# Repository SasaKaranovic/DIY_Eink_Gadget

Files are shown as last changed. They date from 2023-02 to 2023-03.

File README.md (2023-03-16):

# DIY EINK GADGET

## What is this project about?

DIY Multifunctional Eink Gadget (https://youtu.be/i01PoMj23bA "DIY Multifunctional Eink Gadget")

Above video shows the finished E-INK gadget, how it works, how you can build one and motivation behind some of the design decisions.

## I like it! How can I build one?
The above video explains the idea and how hardware and firmware works. It's recommended that you watch that first.
Hardware and firmware build instructions and source files are available in their respective folders.

---

Blog page: https://sasakaranovic.com/projects/diy-eink-gadget/

YouTube video: https://youtu.be/i01PoMj23bA

---

#### Sasa Karanovic

<a href="https://sasakaranovic.com/" target="_blank" title="Sasa Karanovic Home Page"> Home Page</a> &nbsp;&middot;&nbsp; <a href="https://youtube.com/c/sasakaranovic" target="_blank" title="Sasa Karanovic on YouTube"> YouTube</a> &nbsp;&middot;&nbsp; <a href="https://github.com/sasakaranovic" target="_blank" title="Sasa Karanovic on GitHub"> GitHub</a> &nbsp;&middot;&nbsp; <a href="https://twitter.com/_sasakaranovic_" target="_blank" title="Sasa Karanovic on Twitter"> Twitter</a> &nbsp;&middot;&nbsp; <a href="https://instagram.com/_sasakaranovic_" target="_blank" title="Sasa Karanovic on Instagram"> Instagram</a> &nbsp;&middot;&nbsp; <a href="https://buymeacoffee.com/sasakaranovic" target="_blank" title="Sasa Karanovic on Buy me a coffee"> Buy me a coffee</a>

[home]: https://raw.githubusercontent.com/SasaKaranovic/common/master/assets/img_home.png "Sasa Karanovic Home Page"
[youtube]: https://raw.githubusercontent.com/SasaKaranovic/common/master/assets/img_youtube.png "Sasa Karanovic YouTube channel"
[github]: https://raw.githubusercontent.com/SasaKaranovic/common/master/assets/img_github.png "Sasa Karanovic on GitHub"
[twitter]: https://raw.githubusercontent.com/SasaKaranovic/common/master/assets/img_twitter.png "Sasa Karanovic on Twitter"
[instagram]: https://raw.githubusercontent.com/SasaKaranovic/common/master/assets/img_instagram.png "Sasa Karanovic on Instagram"
[coffee]: https://raw.githubusercontent.com/SasaKaranovic/common/master/assets/img_coffee.png "Buy me a coffee"

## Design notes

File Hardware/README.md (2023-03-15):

# Hardware folder contents

Folder structure

    Docs            → Datasheets for nRF microcontroller, display driver, e-ink display etc.
    Release         → Release/manufacturing packages (Gerbers, Pick-and-Place, Bill of Material etc)
    Source files    → Altium Designer Source files
    Schematic Print.PDF
    README.md

Release folder contains manufacturing releases for this project. If you want to order a board, this folder contains gerbers, bill of material, pick and place and any other manufacturing related document.

If you wish to modify the project, source files are available in the Source files folder. You could also use [online viewer](https://www.altium.com/viewer/) to view them online.

For convenience, there is also `Schematic Print.pdf` document that contains all the schematic documents in the `.pdf` format.

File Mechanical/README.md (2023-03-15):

# Mechanical/Enclosure folder contents

Folder structure

    STL         → STL/3MF files, ready for slicing and printing
    Fusion360   → Fusion360 design source file

STL folder contains `.stl` files if you wish to 3D print your own enclosure.

Fusion360 folder contains enclosure design source files that can be imported into Fusion360 if you wish to modify the design or inspect it in more detail.

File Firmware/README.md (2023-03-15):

# Development Environment

We are using nRF Connect SDK with Zephyr RTOS to build our project.

Please follow the Nordic's nRF Connect SDK [getting started guide](https://developer.nordicsemi.com/nRF_Connect_SDK/doc/latest/nrf/getting_started.html) on how to install and setup development environment.

We are using the following SDK and Zephyr version
nRF Connect SDK version: 2.3.99
Zephyr version: 3.2.99

# How to build firmware

Once you have the build environment setup, you can simply navigate to `Firmware` folder and compile the code by running `west build -b nrf52dk_nrf52810` command
After a few seconds you should see a message that looks something like this
```
[183/183] Linking C executable zephyr\zephyr.elf
Memory region         Used Size  Region Size  %age Used
           FLASH:      111484 B       192 KB     56.70%
             RAM:       16936 B        24 KB     68.91%
        IDT_LIST:          0 GB         2 KB      0.00%
```
This means you have succesfully compiled the firmware and you are ready to flash it onto your board.

# How to flash firmware

We are using J-Link programmer to flash firmware onto our boards.
Simply connect the J-Link programmer to your board, provide power to the e-ink gadget and run `west flash` to flash latest binary onto your board.

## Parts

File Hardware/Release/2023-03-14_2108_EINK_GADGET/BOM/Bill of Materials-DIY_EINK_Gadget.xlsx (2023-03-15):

Designator | Description | Distributor | Distributor Part Number | Manufacturer | Manufacturer Part Number | Quantity
A1 | 2.4GHz - Chip RF Antenna 2.4GHz ~ 2.5GHz 0.5dBi Solder Surface Mount | DigiKey | 712-1006-1-ND | Johanson Technology Inc. | 2450AT18B100E | 1
C2, C3, C4, C5 | Capacitor | DigiKey | 1276-2138-1-ND | Samsung Electro-Mechanics | CL10C070DB8NNNC | 4
C6, C7, C8, C12, C25, C27 | Capacitor | DigiKey | 1276-1935-1-ND | Samsung Electro-Mechanics | CL10B104KB8NNWC | 6
C9, C24, C26, C28, C29 | Capacitor | DigiKey | 1276-2087-1-ND | Samsung Electro-Mechanics | CL10B475KQ8NQNC | 5
C11, C15, C16, C17, C18, C19, C20, C21, C22 | Capacitor | DigiKey | 1276-6617-1-ND | Samsung Electro-Mechanics | CL10B105KA8VPNC | 9
C14 | Capacitor | DigiKey | 1276-1008-1-ND | Samsung Electro-Mechanics | CL10C101JB8NNNC | 1
C23 | Capacitor | DigiKey | 1276-2083-1-ND | Samsung Electro-Mechanics | CL10B474KA8NNNC | 1
D1, D2, D3 |  | DigiKey | NRVB130LSFT1GOSCT-ND | onsemi | NRVB130LSFT1G | 3
D4 | Typical RED GaAs LED | DigiKey | Lite-On Inc. | Lite-On Inc. | LTST-C193KRKT-5A | 1
L1, L5 | Inductor | DigiKey | 311-0.0HRCT-ND | YAGEO | RC0603FR-070RL | 2
L2 | Inductor | DigiKey | 535-12249-1-ND | Abracon LLC | ASMCI-0603-100M-T | 1
L3 | Inductor | DigiKey | 535-11540-1-ND | Abracon LLC | AIMC-0603-3N9S-T | 1
L4 | Inductor | DigiKey | 445-8747-1-ND | TDK Corporation | VLCF5024T-470MR40-2 | 1
P2 |  | DigiKey | 609-SFV24R-4STE1HLFCT-ND | Amphenol ICC (FCI) | SFV24R-4STE1HLF | 1
P3 | CONN RCPT USB2.0 TYPEC 5A | DigiKey | 2073-USB4105-GF-ACT-ND | GCT | USB4105-GF-A | 1
Q1 | MOSFET N-CH 60V 0.38A | DigiKey | DMN62D0U-13DICT-ND | Diodes Incorporated | DMN62D0U-13 | 1
R3 | Resistor | DigiKey | 311-2.2HRCT-ND | YAGEO | RC0603FR-072R2L | 1
R4 | Resistor | DigiKey | 13-AC0603FR-1022KLCT-ND | YAGEO | AC0603FR-1022KL | 1
R5 | Resistor | DigiKey | 13-RC0603FR-10470RLCT-ND | YAGEO | RC0603FR-10470RL | 1
R6, R7 | Resistor | DigiKey | 13-RC0603FR-135K1LCT-ND | YAGEO | RC0603FR-135K1L | 2
R10 | Resistor | DigiKey | 311-68.0KHRCT-ND | YAGEO | RC0603FR-0768KL | 1
R11 | Resistor | DigiKey | 311-100KHRCT-ND | YAGEO | RC0603FR-07100KL | 1
SW1, SW2, SW3 | SWITCH TACTILE SPST-NO 0.05A 12V | DigiKey | CKN9088CT-ND | C&K | PTS645SL50SMTR92 LFS | 3
U1 | IC RF TxRx + MCU Bluetooth Bluetooth v5.0 2.4GHz 32-VFQFN Exposed Pad | DigiKey | 1490-NRF52810-QCAA-RCT-ND | Nordic Semiconductor ASA | NRF52810-QCAA-R | 1
U2 | Linear Voltage Regulator IC 1 Output 450mA SOT-23-5 | DigiKey | NCP161ASN330T1GOSCT-ND | ON Semiconductor | NCP161ASN330T1G | 1
U3 | 1xLi-Ion char, 0.5A, 4.2V reg, 3.75-6V | DigiKey | MCP73832T-2ACI/OTCT-ND | Microchip Technology | MCP73832T-2ACI/OT | 1
X1, X2 | 32.768 kHz ±20ppm Crystal 7pF 70 kOhms 2-SMD, No Lead, 32 MHz ±10ppm Crystal 8pF 50 Ohms 4-SMD, No Lead | DigiKey | XC3067CT-ND | ECS Inc. | ECS-320-8-37B-CKY-TR | 2

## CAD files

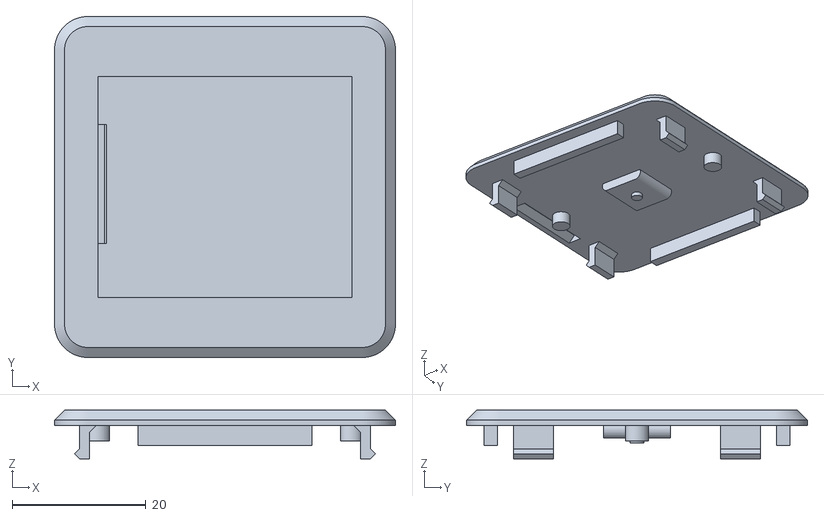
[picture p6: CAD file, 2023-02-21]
Mechanical/STL/Top-Actuator.stl
51.0 x 51.0 x 7.30

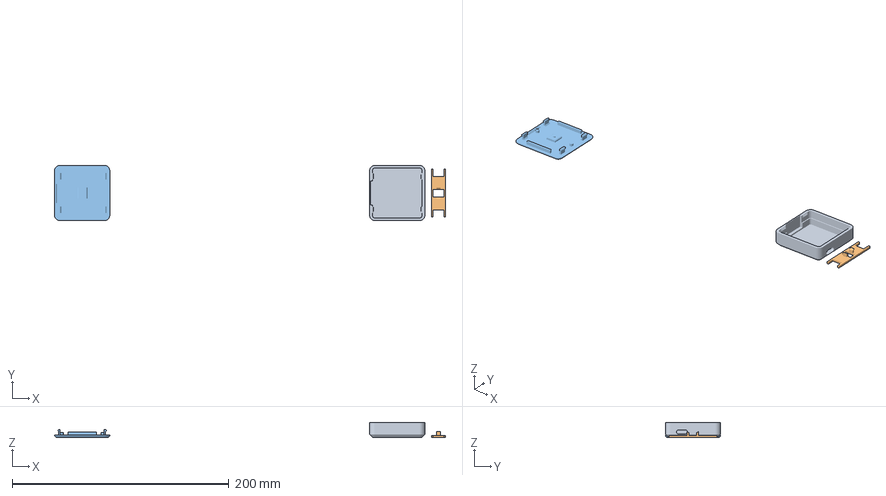
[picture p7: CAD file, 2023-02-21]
Mechanical/STL/Enclosure.3mf
360.5 x 51.0 x 14.0 mm
Bottom Enclosure.stl
Switch-Insert.stl
Top-Actuator.stl

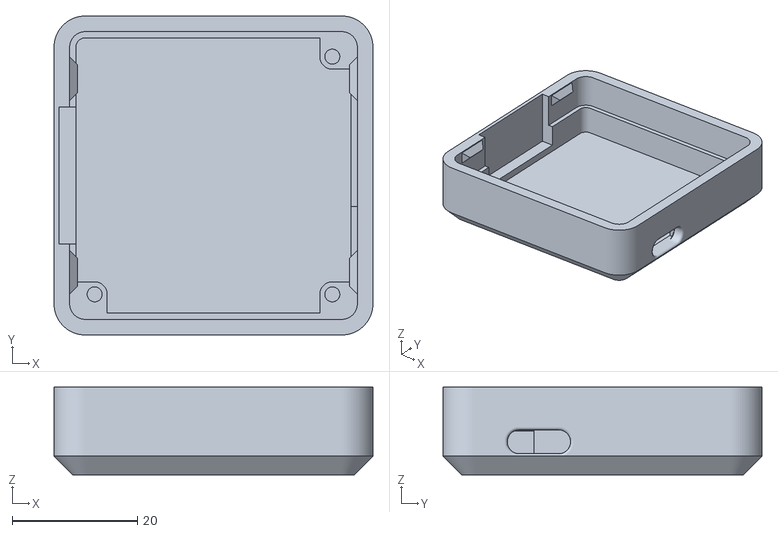
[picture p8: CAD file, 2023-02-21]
Mechanical/STL/Bottom Enclosure.stl
51.0 x 51.0 x 14.0

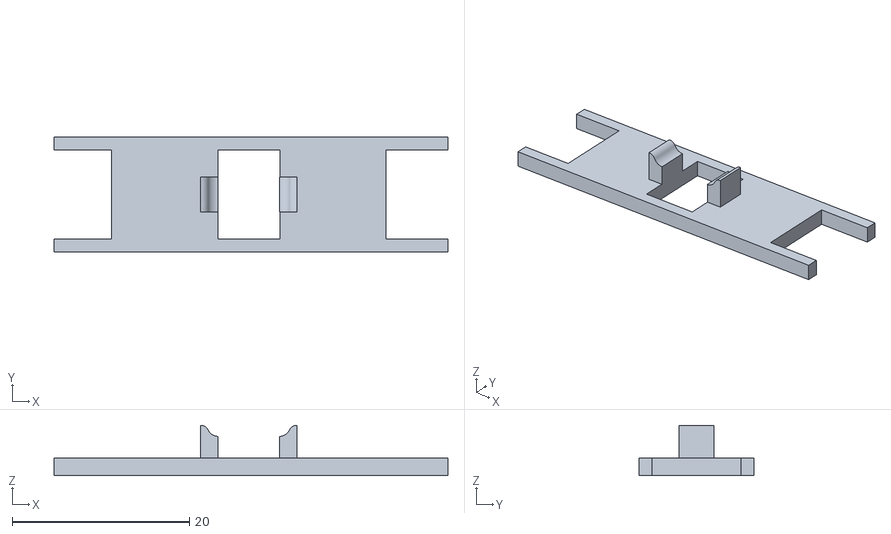
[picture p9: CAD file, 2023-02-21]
Mechanical/STL/Switch-Insert.stl
44.5 x 13.0 x 5.70

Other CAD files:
Mechanical/Fusion360/Enclosure.f3z

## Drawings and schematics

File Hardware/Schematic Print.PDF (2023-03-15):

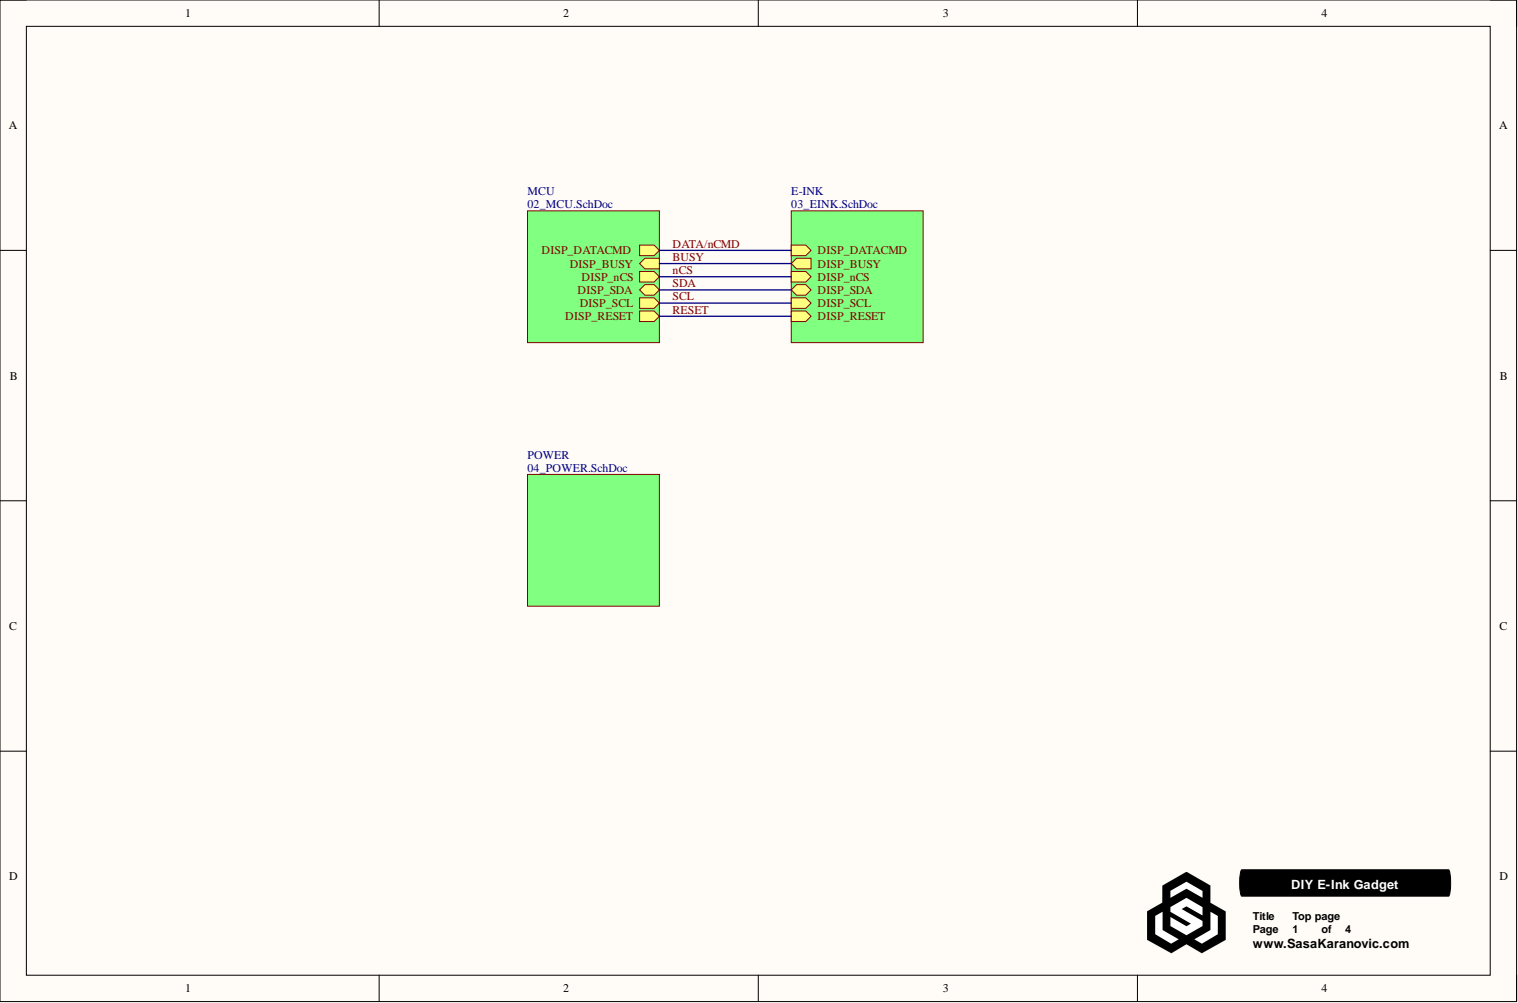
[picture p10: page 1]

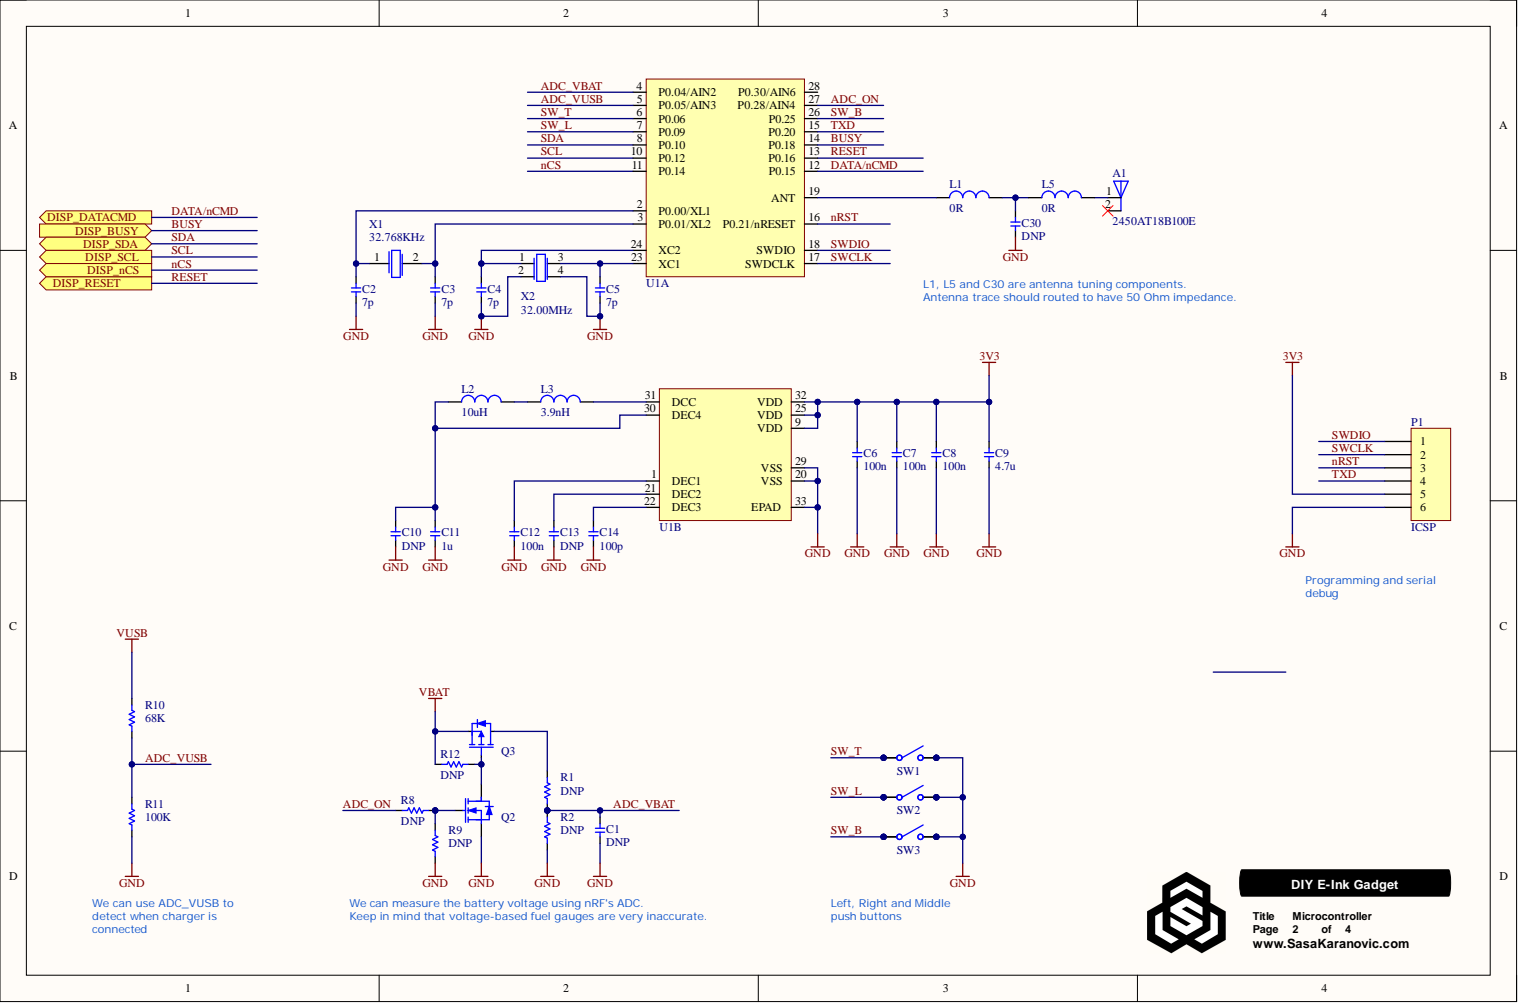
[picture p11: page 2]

C4 7p

L1, L5 and C30 are antenna tuning components.
Antenna trace should routed to have 50 Ohm impedance.

GND
We can use ADC_VUSB to
detect when charger is
connected

We can measure the battery voltage using nRF's ADC.
Keep in mind that voltage-based fuel gauges are very inaccurate.

Left, Right and Middle
push buttons

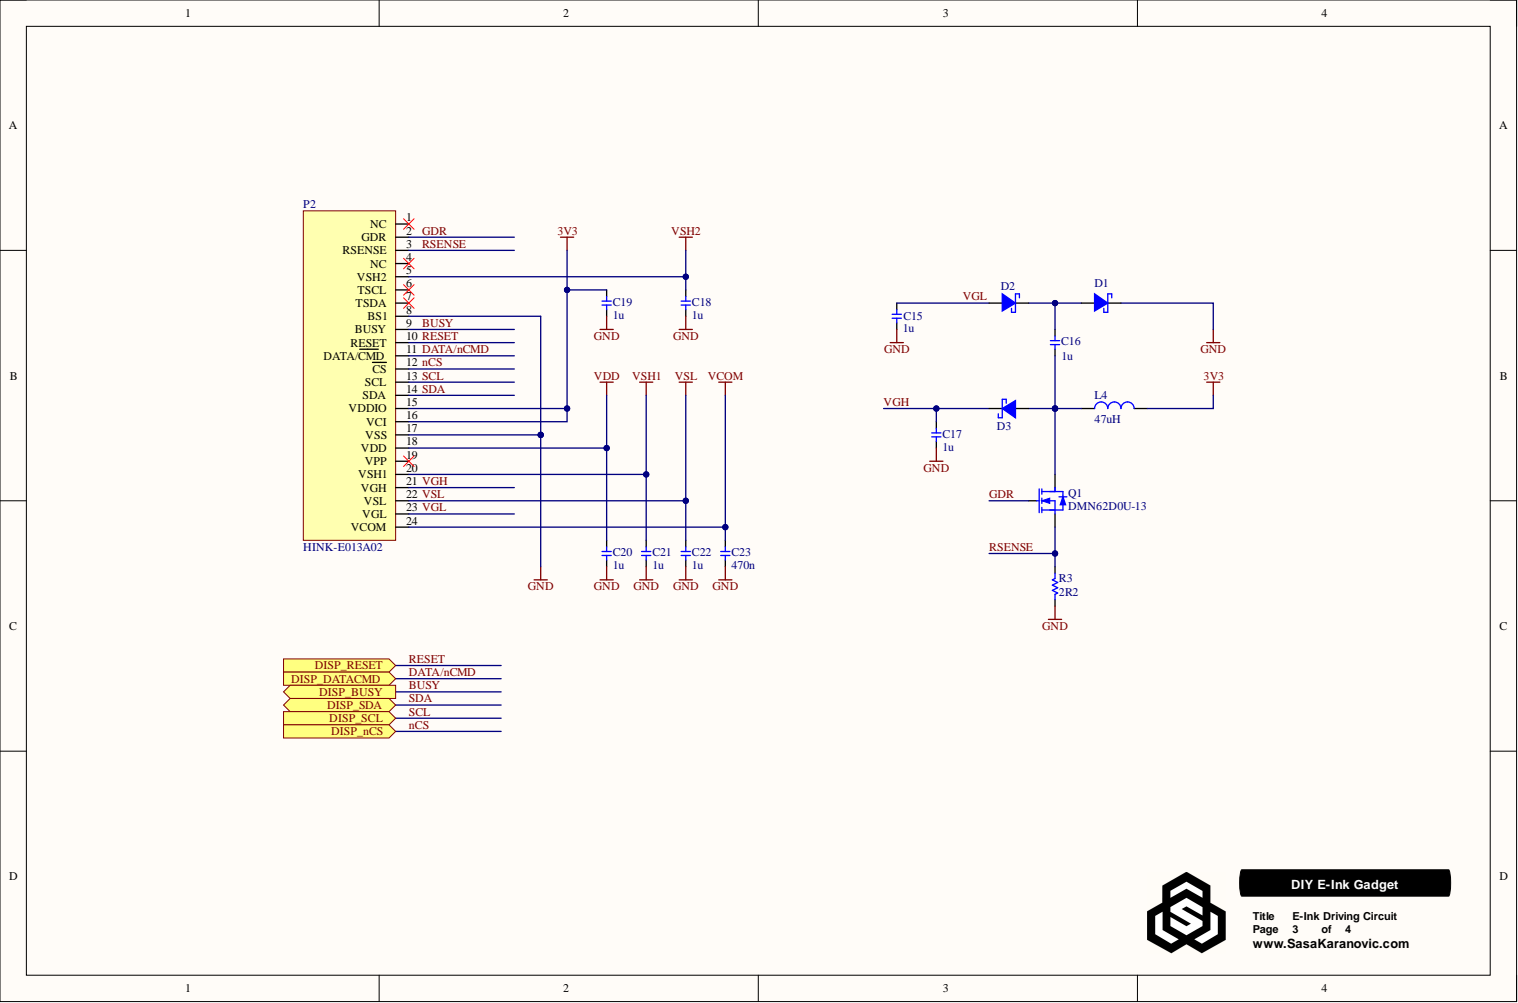
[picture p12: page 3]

9 BU S Y 1 0 RESE T 1 1 D ATA / n C M D 1 2 nCS 1 3 SCL 1 4 SD A

1 5
1 6
1 7
1 8
1 9 0

2 1 V G H 2 2 VSL VGL

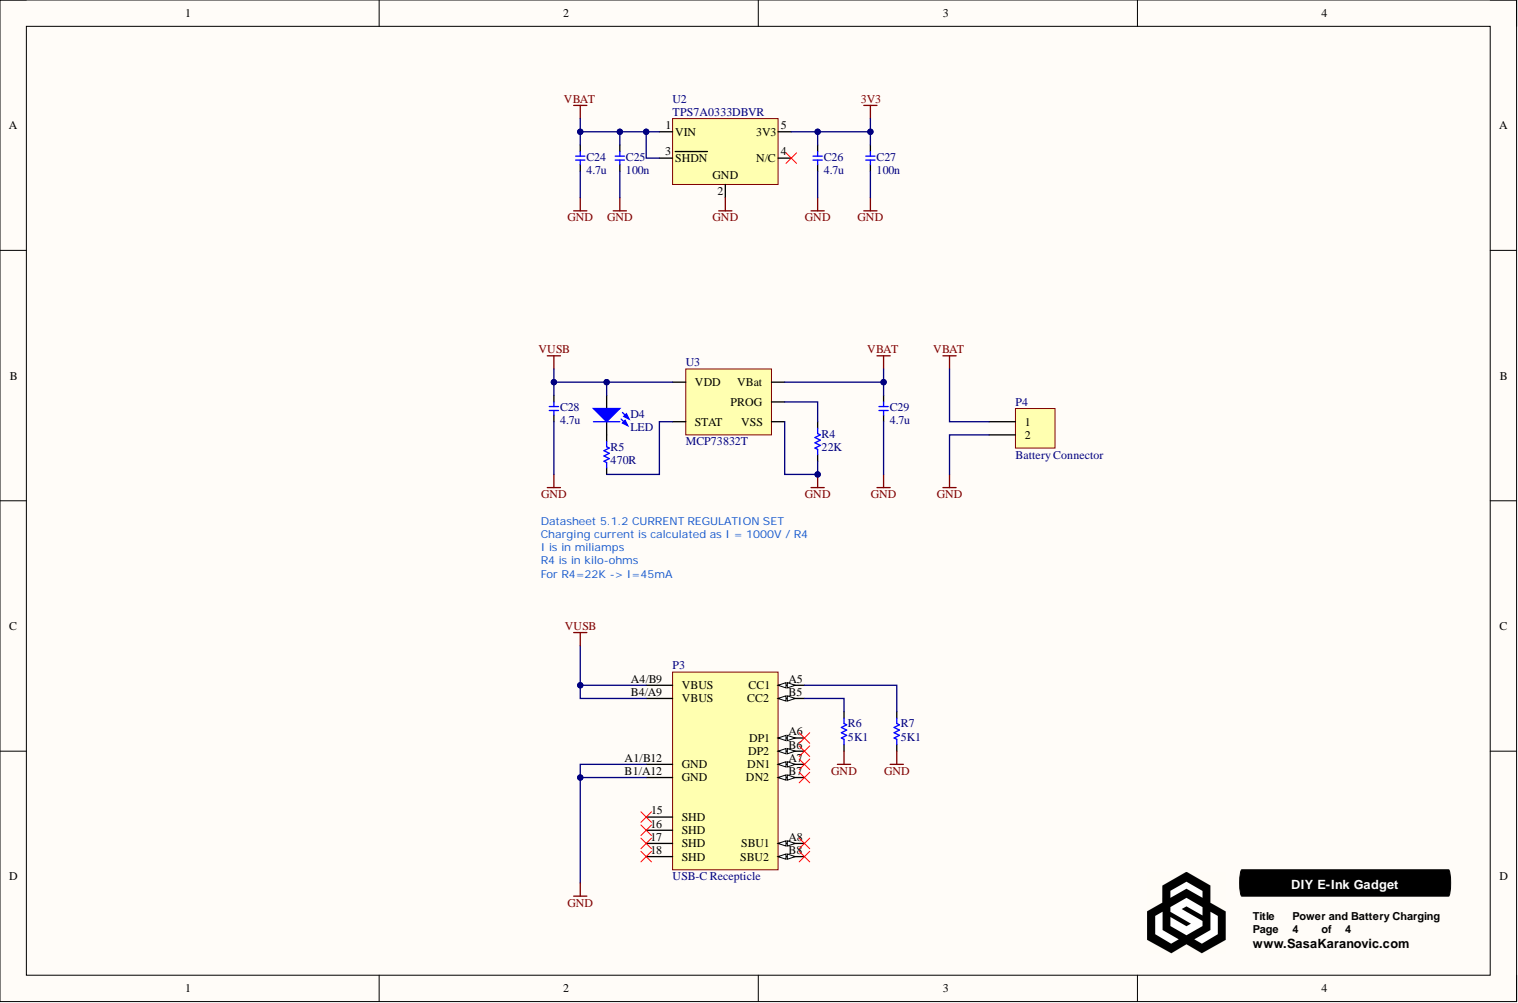
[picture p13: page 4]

Datasheet 5.1.2 CURRENT REGULATION SET
Charging current is calculated as I = 1000V / R4
I is in miliamps
R4 is in kilo-ohms
For R4=22K -> I=45mA

GND B1/A12

SHD 15

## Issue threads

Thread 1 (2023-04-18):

Is this project open source hardware and/or open source software?

abetusk, 2023-04-18:
From the [YouTube video](https://www.youtube.com/watch?v=i01PoMj23bA):

> ... as always the entire project is open source open hardware so you can easily make any changes or improvements ...

As of this writing, this project is, as far as I can tell, "closed source" (at least here in the US) since there is no indication about what license is that the project falls under. I don't see a LICENSE file for the project nor do I see license file headers in the source files. If I've missed these, my apologies.

"Open Source" has a generally accepted meaning of being able to use the digital artifacts for commercial purposes. The [OSI](https://opensource.org/osd/) and Wikipedia's entry on [open-source licensing](https://en.wikipedia.org/wiki/Open-source_license) both articulate that commercial re-use is a (generally accepted) requirement of an "open source" license.

The [Open Source Hardware Association](https://www.oshwa.org/definition/) articulates requirements of design files to meet their "open source" standards:

> Open source hardware is hardware whose design is made publicly available so that anyone can study, modify, distribute, make, and sell the design or hardware based on that design.

Without licensing information about the various digital artifacts (BOM, schematic, Gerbers, source code, etc.), the default is for them to fall under copyright protection and are not allowed to be copied, modified or distributed without explicit consent.

Was the intent to make this project libre/free/open source software/hardware?

If so, could you indicate the license, either by providing a LICENSE file with the appropriate license or by putting a license preamble in each of the source files (preferably both).

If not, it might be good to clarify what the restrictions are to avoid confusion. For example, indicating that the source is available, rather than it being open source.

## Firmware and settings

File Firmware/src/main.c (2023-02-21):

#include <zephyr/logging/log.h>
LOG_MODULE_REGISTER(app, LOG_LEVEL_INF);

#include <zephyr/kernel.h>
#include <zephyr/device.h>
#include <zephyr/devicetree.h>
#include <zephyr/init.h>
#include <zephyr/pm/pm.h>
#include <zephyr/pm/device.h>
#include <zephyr/pm/policy.h>
#include <soc.h>
#include "retained.h"
#include <stdio.h>
#include <string.h>
#include "board.h"
#include "ssd1680.h"
#include "gfx.h"
#include "gfx_icon.h"
#include "screen_controller.h"
#include "screen_game_dashboard.h"

/* Prevent deep sleep (system off) from being entered on long timeouts
 * or `K_FOREVER` due to the default residency policy.
 *
 * This has to be done before anything tries to sleep, which means
 * before the threading system starts up between PRE_KERNEL_2 and
 * POST_KERNEL.  Do it at the start of PRE_KERNEL_2.
 */
static int disable_ds_1(const struct device *dev)
{
    ARG_UNUSED(dev);
    pm_policy_state_lock_get(PM_STATE_SOFT_OFF, PM_ALL_SUBSTATES);
    return 0;
}

SYS_INIT(disable_ds_1, PRE_KERNEL_2, 0);

static void reset_to_main_menu(void)
{
    LOG_INF("Resetting to setup menu");
    retained.app_state = 0;             // Reset app state to main-menu
    retained.current_selection = 1;     // Set first menu item as selected
    retained_update();                  // Update retained section
    button_state.left = false;          // Clear left button press
    button_state.middle = false;        // Clear middle button press
    button_state.right = false;         // Clear right button press
}

void main(void)
{
    // Wake up time is 16.8us so we should be able to capture button press
    // First get the GPIO state before going forward
    board_switch_init();
    board_update_button_states();

    // Initialize rest of the board
    board_gpio_init();
    gfx_initialize();

    // Validate retained data
    bool retained_ok = retained_validate();
    retained.boots += 1;
    retained_update();

    LOG_INF("Left: %s", button_state.left ? "On" : "Off");
    LOG_INF("Middle: %s", button_state.middle ? "On" : "Off");
    LOG_INF("Right: %s", button_state.right ? "On" : "Off");

    LOG_INF("Retained data: %s", retained_ok ? "valid" : "INVALID");
    LOG_INF("Boot count: %u", retained.boots);
    LOG_INF("Off count: %u", retained.off_count);
    LOG_INF("App state: %u", retained.app_state);
    LOG_INF("Selection: %u", retained.current_selection);

    // Check if middle button is held for 3+ sec
    uint8_t nMiddleCount=0;
    while( board_button_is_pressed(BUTTON_MIDDLE) )
    {
        nMiddleCount++;
        k_sleep(K_MSEC(500));
        if(nMiddleCount>=6)
        {
            reset_to_main_menu();
            break;
        }
    }

    // Update the screen based on state of the device
    screen_logic_state_tick();

    // Put screen and the device into deep sleep
    eink_deep_sleep();
    LOG_INF("Entering deep sleep mode. Night night.");
    pm_state_force(0u, &(struct pm_state_info){PM_STATE_SOFT_OFF, 0, 0});

    while (1)
    {
        k_sleep(K_MSEC(500));
    }
}

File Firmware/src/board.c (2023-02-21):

#include <zephyr/logging/log.h>
LOG_MODULE_REGISTER(board, LOG_LEVEL_INF);

#include <zephyr/kernel.h>
#include <zephyr/device.h>
#include <zephyr/devicetree.h>
#include <zephyr/drivers/gpio.h>
#include <zephyr/drivers/spi.h>
#include <hal/nrf_gpio.h>
#include <stdio.h>
#include <string.h>
#include "board.h"

#define SPIBB_NODE  DT_NODELABEL(spibb0)
static const struct device *const dev_spibb = DEVICE_DT_GET(SPIBB_NODE);

#define LED0_NODE DT_ALIAS(led0)
static const struct gpio_dt_spec led = GPIO_DT_SPEC_GET(LED0_NODE, gpios);

#define EINK_RESET DT_ALIAS(einkreset)
static const struct gpio_dt_spec dev_eink_reset = GPIO_DT_SPEC_GET(EINK_RESET, gpios);

#define EINK_BUSY DT_ALIAS(einkbusy)
static const struct gpio_dt_spec dev_eink_busy = GPIO_DT_SPEC_GET(EINK_BUSY, gpios);

#define EINK_DC DT_ALIAS(einkdc)
static const struct gpio_dt_spec dev_eink_dc = GPIO_DT_SPEC_GET(EINK_DC, gpios);


struct spi_cs_control cs_ctrl = (struct spi_cs_control){
    .gpio = GPIO_DT_SPEC_GET(SPIBB_NODE, cs_gpios),
    .delay = 0u,
};


// Buttons
#define SW_COUNT    3
static const struct gpio_dt_spec buttons[SW_COUNT] = {
    GPIO_DT_SPEC_GET_OR(DT_ALIAS(sw0), gpios, {0}),
    GPIO_DT_SPEC_GET_OR(DT_ALIAS(sw1), gpios, {0}),
    GPIO_DT_SPEC_GET_OR(DT_ALIAS(sw2), gpios, {0}),
};

struct board_buttons_s button_state;

int board_switch_init(void)
{
    int ret;
    // Buttons
    for (uint8_t i=0; i<SW_COUNT; i++)
    {
        if (!device_is_ready(buttons[i].port)) {
            printk("Error: button device %s is not ready\n",
                   buttons[i].port->name);
            return -1;
        }

        ret = gpio_pin_configure_dt(&buttons[i], GPIO_INPUT | GPIO_PULL_UP);
        if (ret != 0) {
            printk("Error %d: failed to configure %s pin %d\n",
                   ret, buttons[i].port->name, buttons[i].pin);
            return ret;
        }
    }

    return ret;
}

int board_gpio_init(void)
{
    LOG_DBG("Setting up board");
    int ret;

    // EINK
    LOG_DBG("Setting up EINK display");
    ret = gpio_pin_configure_dt(&dev_eink_busy, GPIO_INPUT);
    if (ret < 0) {
        return ret;
    }
    ret = gpio_pin_configure_dt(&dev_eink_reset, GPIO_OUTPUT_ACTIVE);
    if (ret < 0) {
        return ret;
    }
    ret = gpio_pin_configure_dt(&dev_eink_dc, GPIO_OUTPUT_ACTIVE);
    if (ret < 0) {
        return ret;
    }

    // LED
    LOG_DBG("Setting up activity LED");
    ret = gpio_pin_configure_dt(&led, GPIO_OUTPUT_ACTIVE);
    if (ret < 0) {
        return ret;
    }


    for (uint8_t i=0; i<SW_COUNT; i++)
    {
        /* Configure to generate PORT event (wakeup) on button press. */
        nrf_gpio_cfg_input(buttons[i].pin, NRF_GPIO_PIN_PULLUP);
        nrf_gpio_cfg_sense_set(buttons[i].pin, NRF_GPIO_PIN_SENSE_LOW);
    }


    return 0;
}

bool board_button_is_pressed(board_button_t button)
{
    int val=0;
    val = gpio_pin_get_dt(&buttons[button]);

    if (val)
    {
        return true;
    }
    return false;
}

void board_update_button_states(void)
{
    button_state.left   = board_button_is_pressed(BUTTON_LEFT);
    button_state.middle = board_button_is_pressed(BUTTON_MIDDLE);
    button_state.right  = board_button_is_pressed(BUTTON_RIGHT);
}

void board_led_act_toggle(void)
{
    gpio_pin_toggle_dt(&led);
}

void board_gpio_reset(uint8_t state)
{
    gpio_pin_set_dt(&dev_eink_reset, state);
}
void board_gpio_data_cmd(uint8_t state)
{
    gpio_pin_set_dt(&dev_eink_dc, state);
}

bool board_gpio_busy(void)
{
    if (gpio_pin_get_dt(&dev_eink_busy)==1)
    {
        return true;
    }
    return false;
}



int spi_transfer(uint8_t *data, uint32_t nDataLen)
{
    int ret;
    struct spi_config config;

    config.frequency = 1000000;
    config.operation = SPI_OP_MODE_MASTER | SPI_WORD_SET(8);
    config.slave = 0;
    config.cs = &cs_ctrl;

    struct spi_buf tx_buf[1] = {
        {.buf = data, .len = nDataLen},
    };

    struct spi_buf_set tx_set = { .buffers = tx_buf, .count = nDataLen };

    ret = spi_write(dev_spibb, &config, &tx_set);

    return ret;
}

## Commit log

2023-03-15 Adding new (2023-03-14) release package.
    [02_MCU.SchDoc, Bill of Materials-DIY_EINK_Gadget.xlsx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]
2023-03-15 Adding release files.
    [01_TOP.SchDoc, 02_MCU.SchDoc, 03_EINK.SchDoc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]
